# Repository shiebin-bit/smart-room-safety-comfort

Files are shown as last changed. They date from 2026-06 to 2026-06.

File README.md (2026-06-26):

# Smart Room Safety & Comfort Monitoring System

ESP32-based IoT prototype for monitoring room safety and comfort conditions. The system reads temperature, humidity, gas, light and sound signals, shows local status on an OLED display, sends readings to a Flask backend, stores data in SQLite and provides a web dashboard for live monitoring, history and actuator control.

## Features

- Register and login for dashboard users, with password validation
- Multi-device dashboard with pairing-code onboarding
- Live dashboard for latest sensor readings
- Room status classification: `NORMAL`, `WARNING` and `CRITICAL`
- Historical charts for temperature, gas, light and sound
- CSV export for stored sensor history
- SQLite storage with recent data table and summary values
- AUTO and MANUAL control for relay and buzzer output
- Settings drawer for room name, device name, thresholds, LDR dark state and upload interval
- ESP32 captive setup portal for Wi-Fi and pairing code configuration
- Remote WiFi scan, WiFi switch and saved-profile display from the cloud dashboard
- ESP32 OLED display with sensor, status and connection pages
- Push button for changing OLED pages and long-press Wi-Fi setup reset

## Project Structure

```text
.
├── app.py                         Flask API and SQLite backend
├── requirements.txt               Python dependencies
├── SmartRoomSafetyComfort/        ESP32 Arduino sketch
├── static/                        Dashboard CSS and JavaScript
├── templates/                     Flask HTML template
├── circuit/                       Fritzing circuit source and exported diagram image
└── screenshots/                   Dashboard or testing screenshots
```

Generated files such as `smart_room.db`, `logs/`, `.venv/` and `report/` are ignored by Git.

## Hardware

| Component | Connection / Pin |
|---|---|
| ESP32 30-pin Type-C | Main controller |
| OLED SSD1306 | SDA GPIO21, SCL GPIO22, VCC 3.3V, GND |
| DHT11 | OUT GPIO4, VCC 3.3V, GND |
| MQ-2 smoke and gas sensor | AO GPIO34, VCC 5V, GND |
| LDR light sensor module | DO GPIO35, VCC 3.3V, GND |
| Sound sensor module | OUT GPIO32, VCC 3.3V, GND |
| Push button | GPIO27 to GND, uses `INPUT_PULLUP` |
| Active buzzer | GPIO26, GND |
| 1-channel relay module | IN GPIO14, VCC 3.3V, GND |

The relay load should be connected through `COM` and `NO` so the fan or output device stays off by default and turns on only when the relay is activated.

## Power Rails

| Rail | Use |
|---|---|
| 3.3V | OLED, DHT11, LDR, sound sensor and relay |
| 5V/VIN | MQ-2 gas sensor |
| GND | Common ground for all modules |

The relay module was powered from 3.3V in the final prototype because it switched more reliably with the ESP32 GPIO14 output.

The Fritzing source file and exported circuit image are stored in `circuit/`.

## Arduino Setup

Install these libraries from Arduino IDE Library Manager:

- Adafruit SSD1306
- Adafruit GFX Library
- DHT sensor library
- Adafruit Unified Sensor

Use `ESP32 Dev Module` or an equivalent ESP32 DevKit board in Arduino IDE.

The Arduino sketch no longer stores a fixed Wi-Fi SSID, password or laptop IP address in code. On first boot, or after a long press on the push button, the ESP32 starts a setup Wi-Fi network.

1. Upload `SmartRoomSafetyComfort/SmartRoomSafetyComfort.ino`.
2. Open the cloud dashboard at `https://smartroomsafety.shiebindev.com`.
3. Register or login, then click **Add Device**.
4. Copy the pairing code shown by the dashboard.
5. Connect a phone or laptop to the ESP32 setup WiFi, for example `SmartRoom-Setup-xxxx`.
6. The captive portal should open automatically. If it does not, open `http://192.168.4.1`.
7. Select the home WiFi, enter the WiFi password and enter the pairing code.
8. Save and let the ESP32 restart.

The ESP32 sends the pairing code to the Cloudflare backend:

```text
https://smartroomsafety.shiebindev.com
```

After successful pairing, the backend returns the device ID and device token. The ESP32 saves WiFi credentials and device credentials in flash memory using `Preferences`, so the user only needs to configure it once unless the WiFi changes.

## Dashboard Backend

Run the Flask backend from this folder:

```powershell
python -m venv .venv
.\.venv\Scripts\Activate.ps1
pip install -r requirements.txt
python app.py
```

Open the local dashboard:

```text
http://localhost:5000
```

For a public or long-running demo, set a Flask secret key before starting the server:

```powershell
$env:SMARTROOM_SECRET_KEY="change-this-to-a-long-random-value"
$env:SMARTROOM_BACKEND_URL="https://smartroomsafety.shiebindev.com"
python app.py
```

For a phone or ESP32 outside the laptop, expose the Flask server through Cloudflare Tunnel. The ESP32 sketch already uses the project domain internally, so general users do not type the backend URL during setup.

```powershell
cloudflared tunnel --url http://localhost:5000
```

For this project, the permanent Cloudflare route should point to the Flask server:

```text
smartroomsafety.shiebindev.com -> http://localhost:5000
```

## API Endpoints

| Endpoint | Method | Purpose |
|---|---|---|
| `/` | GET | Web dashboard |
| `/login` | GET/POST | User login page |
| `/register` | GET/POST | User registration page |
| `/api/me` | GET | Current dashboard user |
| `/api/devices` | GET/POST | List or add owned ESP32 devices |
| `/api/devices/<device_id>` | PATCH | Update device name and room |
| `/api/device-pair` | POST | Exchange ESP32 pairing code for device credentials |
| `/api/sensor-data` | POST | Receive ESP32 sensor data |
| `/api/latest` | GET | Return latest stored reading |
| `/api/history` | GET | Return historical readings |
| `/api/history/export.csv` | GET | Export selected device history |
| `/api/summary` | GET | Return stored-data summary |
| `/api/settings` | GET/POST | Read or update thresholds and configuration |
| `/api/control` | GET/POST | Read or update relay, buzzer and control mode |
| `/api/device-command` | GET | Plain-text command endpoint for ESP32 |
| `/api/device-status` | POST | Receive WiFi status, scan results and events |
| `/api/wifi/scan` | POST | Queue remote WiFi scan |
| `/api/wifi/connect` | POST | Queue remote WiFi switch |
| `/api/wifi/reconnect` | POST | Queue reconnect using a WiFi profile saved on ESP32 |
| `/api/wifi/forget` | POST | Queue saved WiFi deletion |

## Control Logic

AUTO mode:

```text
NORMAL   -> relay OFF
WARNING  -> relay OFF
CRITICAL -> relay ON
```

MANUAL mode:

```text
Relay switch ON  -> relay output ON
Relay switch OFF -> relay output OFF
Buzzer enabled   -> buzzer can sound in AUTO, or directly controls buzzer in MANUAL
```

## Notes

- LDR module behavior in this prototype is `LOW = bright` and `HIGH = dark`.
- GPIO34 is input-only and is used for MQ-2 analog output.
- GPIO35 is input-only and is used for LDR digital output.
- WiFi passwords are stored locally on the ESP32 after setup. The dashboard only stores SSID names, signal/status data and temporary command state.
- Device tokens are generated by the backend after pairing. Only token hashes are stored in SQLite.
- The report files are intentionally excluded from the GitHub repository.

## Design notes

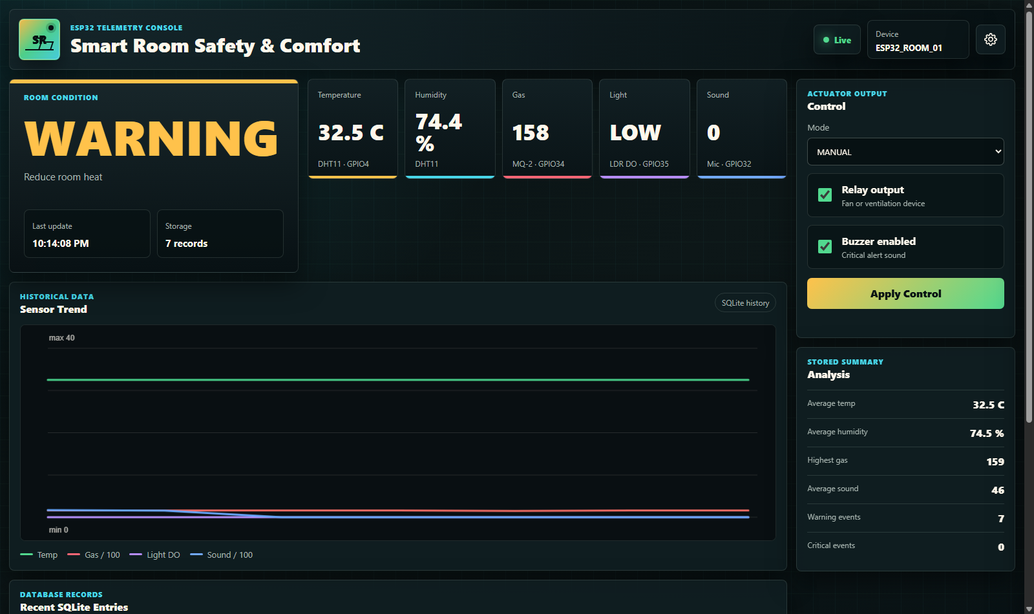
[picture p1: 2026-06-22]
screenshots/dashboard-redesign.png

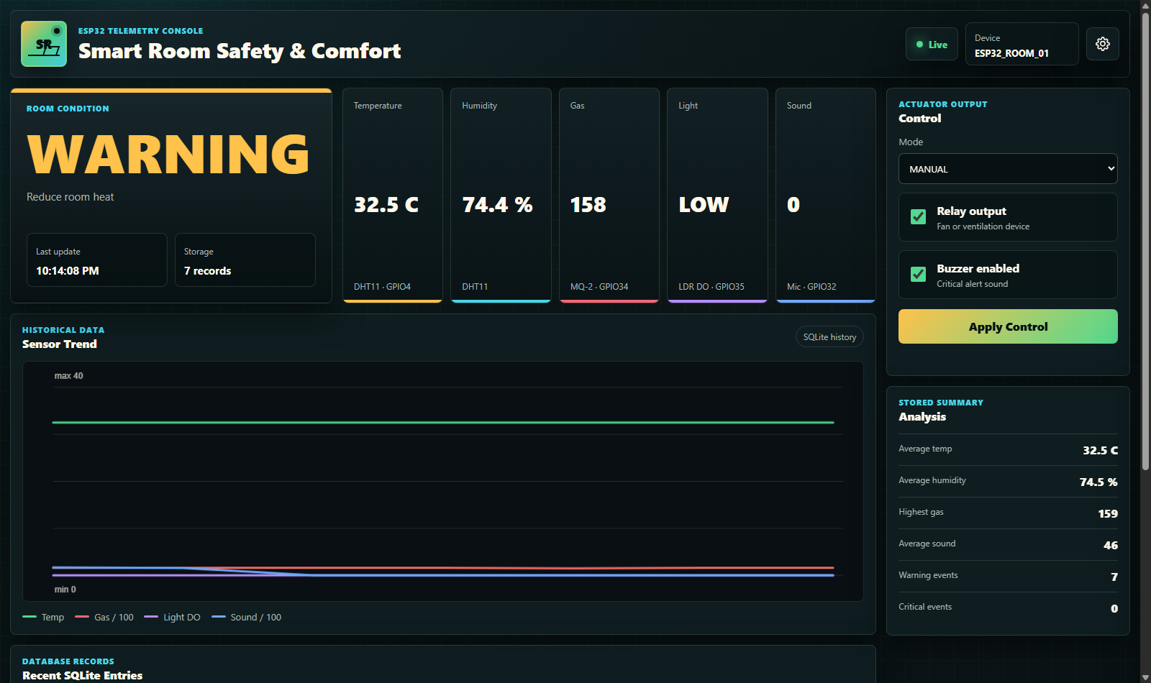
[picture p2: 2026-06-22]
screenshots/dashboard-redesign-final.png

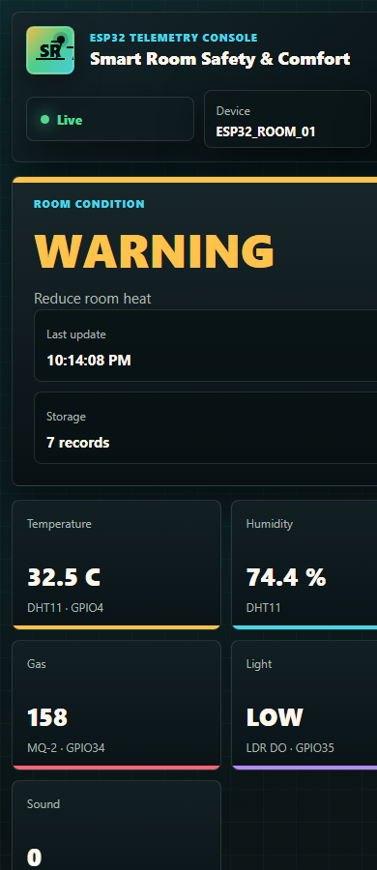
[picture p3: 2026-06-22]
screenshots/dashboard-redesign-mobile.png

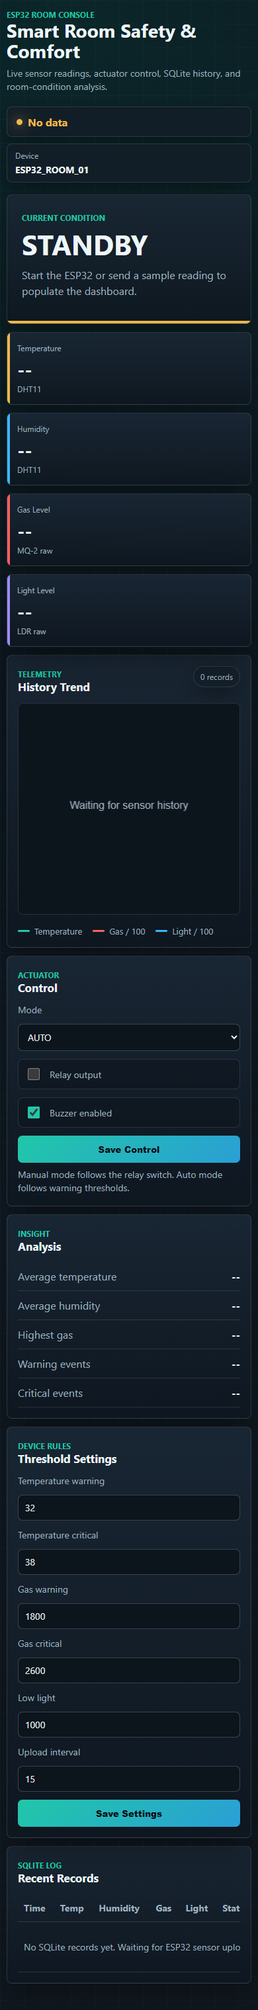
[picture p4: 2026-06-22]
screenshots/dashboard/dashboard-mobile2.png

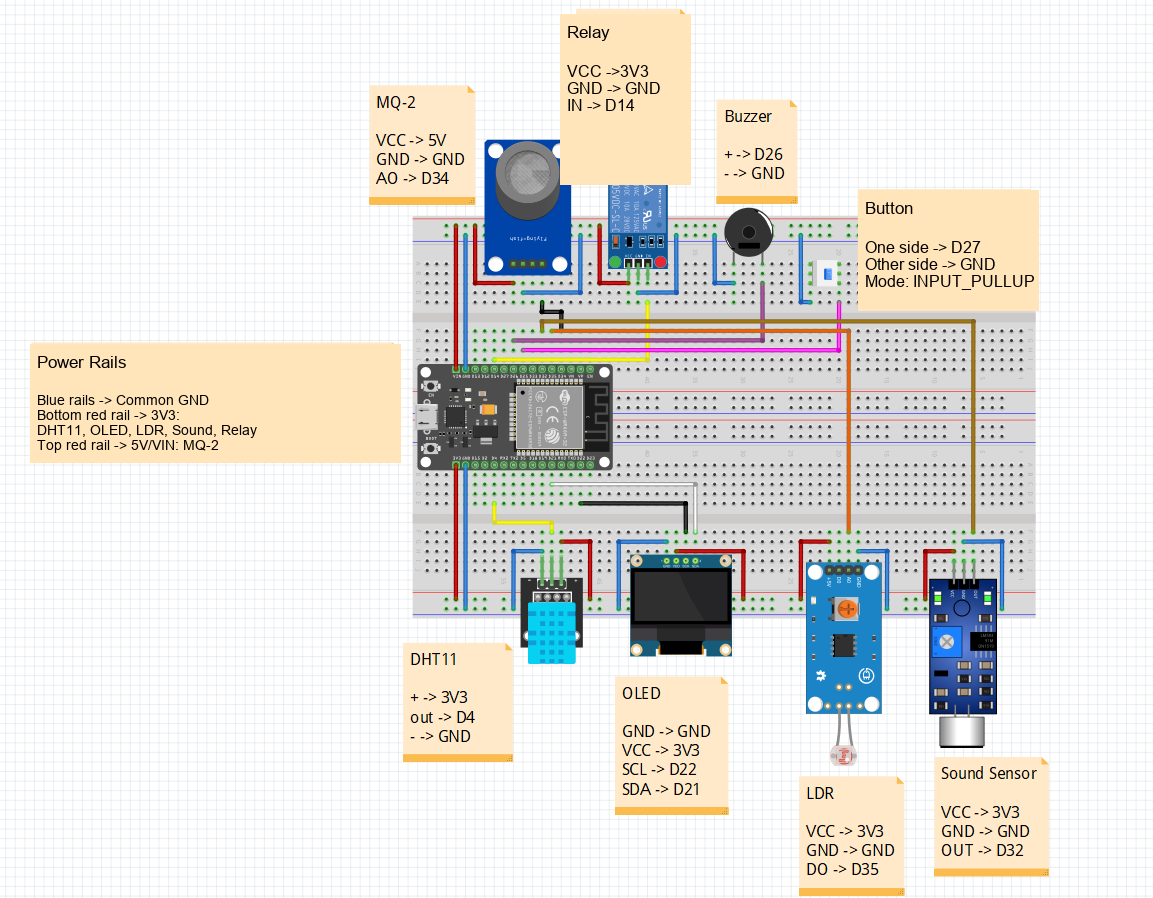
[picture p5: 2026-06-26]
circuit/fritzing-circuit-diagram.png

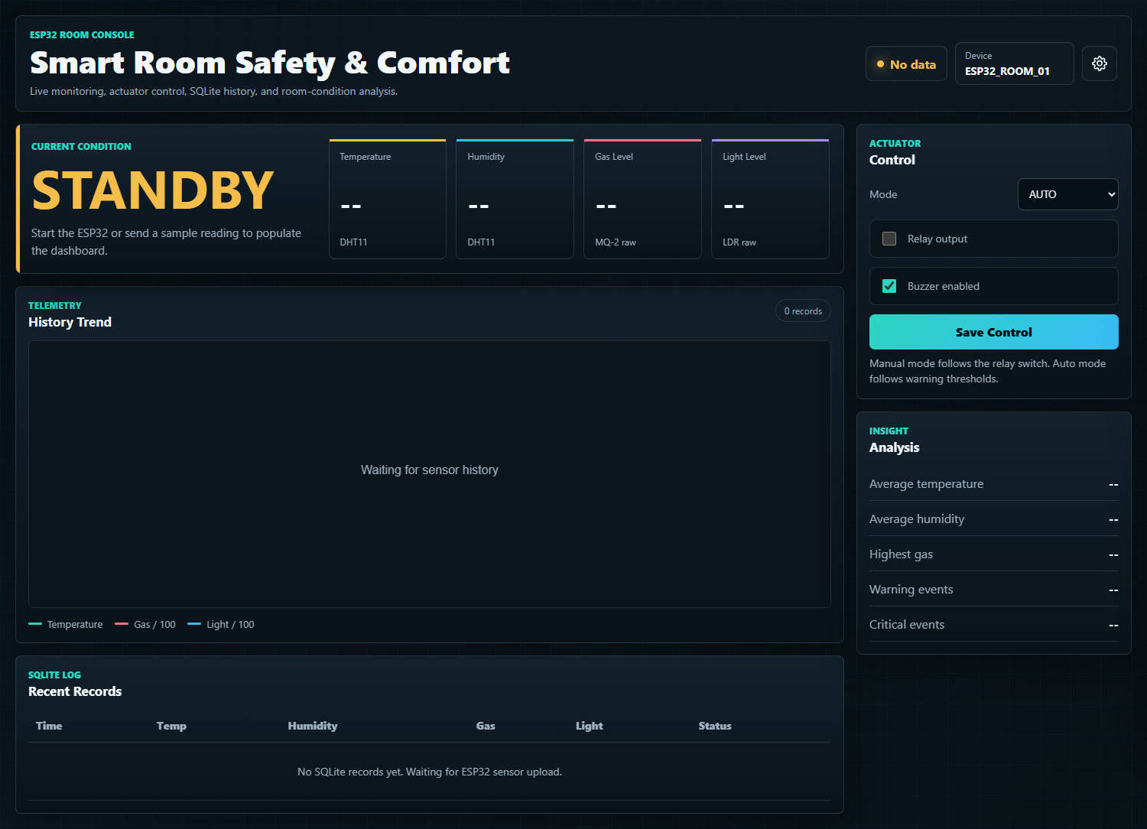
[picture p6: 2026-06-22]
screenshots/dashboard/dashboard-desktop-closed.png

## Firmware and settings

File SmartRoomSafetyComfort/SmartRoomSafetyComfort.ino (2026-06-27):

#include <WiFi.h>
#include <WebServer.h>
#include <DNSServer.h>
#include <HTTPClient.h>
#include <WiFiClientSecure.h>
#include <Preferences.h>
#include <Wire.h>
#include <Adafruit_GFX.h>
#include <Adafruit_SSD1306.h>
#include <DHT.h>

#define OLED_SDA_PIN 21
#define OLED_SCL_PIN 22

#define DHT_PIN 4
#define DHT_TYPE DHT11

#define MQ2_ANALOG_PIN 34
#define LDR_DIGITAL_PIN 35
#define SOUND_DIGITAL_PIN 32

#define BUTTON_PIN 27
#define BUZZER_PIN 26
#define RELAY_PIN 14

const bool RELAY_ACTIVE_LOW = true;

#define SCREEN_WIDTH 128
#define SCREEN_HEIGHT 64
#define OLED_RESET -1
#define OLED_ADDR 0x3C

Adafruit_SSD1306 display(SCREEN_WIDTH, SCREEN_HEIGHT, &Wire, OLED_RESET);
DHT dht(DHT_PIN, DHT_TYPE);
WebServer setupServer(80);
DNSServer dnsServer;
Preferences preferences;
WiFiClientSecure secureClient;

const byte DNS_PORT = 53;
const char *DEFAULT_BACKEND_BASE_URL = "https://smartroomsafety.shiebindev.com";
const char *SAVED_WIFI_PASSWORD_MARKER = "__SAVED_WIFI_PROFILE__";

String wifiSsid = "";
String wifiPassword = "";
String pairingCode = "";
String backendBaseUrl = DEFAULT_BACKEND_BASE_URL;
String deviceId = "UNPAIRED";
String deviceToken = "";

float tempWarningC = 35.0;
float tempCriticalC = 40.0;

int gasWarningRaw = 1800;
int gasCriticalRaw = 2600;
int ldrDarkState = HIGH;

float temperatureC = 0;
float humidityPct = 0;
int gasRaw = 0;
int lightRaw = HIGH;
int soundRaw = 0;

String roomStatus = "STARTING";
String recommendation = "Checking sensors";
String controlMode = "AUTO";

bool manualRelayCommand = false;
bool relayOutputOn = false;
bool buzzerEnabled = true;
bool buzzerShouldAlert = false;
bool buzzerShouldCritical = false;

int oledPage = 0;
const int OLED_PAGE_COUNT = 3;

unsigned long lastSensorReadMs = 0;
unsigned long lastOledUpdateMs = 0;
unsigned long lastUploadMs = 0;
unsigned long lastCommandFetchMs = 0;
unsigned long lastWiFiRetryMs = 0;
unsigned long lastPairRetryMs = 0;
unsigned long lastStatusPostMs = 0;
unsigned long lastButtonChangeMs = 0;
unsigned long buttonPressedAtMs = 0;
unsigned long uploadIntervalMs = 5000;

bool lastButtonReading = HIGH;
bool stableButtonState = HIGH;
bool longPressHandled = false;
bool setupPortalRunning = false;
bool setupSaveRequested = false;

const unsigned long SENSOR_INTERVAL_MS = 2000;
const unsigned long OLED_INTERVAL_MS = 500;
const unsigned long COMMAND_INTERVAL_MS = 5000;
const unsigned long WIFI_RETRY_INTERVAL_MS = 15000;
const unsigned long PAIR_RETRY_INTERVAL_MS = 15000;
const unsigned long STATUS_INTERVAL_MS = 15000;
const unsigned long BUTTON_DEBOUNCE_MS = 50;
const unsigned long BUTTON_LONG_PRESS_MS = 8000;
const int WIFI_PROFILE_COUNT = 6;

void setRelay(bool on);
void setBuzzer(bool on);

void loadDeviceConfig() {
  preferences.begin("smartroom", true);
  wifiSsid = preferences.getString("ssid", "");
  wifiPassword = preferences.getString("password", "");
  pairingCode = preferences.getString("pairing", "");
  backendBaseUrl = preferences.getString("backend", DEFAULT_BACKEND_BASE_URL);
  deviceId = preferences.getString("device_id", "UNPAIRED");
  deviceToken = preferences.getString("token", "");
  preferences.end();
}

void saveSetupConfig(const String &ssid, const String &password, const String &code) {
  String cleanCode = code;
  cleanCode.trim();
  preferences.begin("smartroom", false);
  preferences.putString("ssid", ssid);
  preferences.putString("password", password);
  if (cleanCode.length() > 0) {
    preferences.putString("pairing", cleanCode);
  }
  preferences.putString("backend", DEFAULT_BACKEND_BASE_URL);
  preferences.end();
}

void saveDeviceCredentials(const String &newDeviceId, const String &newToken) {
  String cleanDeviceId = newDeviceId;
  cleanDeviceId.trim();
  String cleanToken = newToken;
  cleanToken.trim();
  preferences.begin("smartroom", false);
  preferences.putString("device_id", cleanDeviceId);
  preferences.putString("token", cleanToken);
  preferences.putString("pairing", "");
  preferences.putString("backend", DEFAULT_BACKEND_BASE_URL);
  preferences.end();
  deviceId = cleanDeviceId;
  deviceToken = cleanToken;
  pairingCode = "";
}

void clearSavedWiFiOnly() {
  preferences.begin("smartroom", false);
  preferences.putString("ssid", "");
  preferences.putString("password", "");
  preferences.end();
  wifiSsid = "";
  wifiPassword = "";
}

void factoryResetDevice() {
  Serial.println("Factory reset requested. Clearing saved WiFi, pairing and device credentials.");
  WiFi.disconnect(true, true);
  preferences.begin("smartroom", false);
  preferences.clear();
  preferences.end();
  wifiSsid = "";
  wifiPassword = "";
  pairingCode = "";
  backendBaseUrl = DEFAULT_BACKEND_BASE_URL;
  deviceId = "UNPAIRED";
  deviceToken = "";
  controlMode = "AUTO";
  manualRelayCommand = false;
  relayOutputOn = false;
  buzzerEnabled = true;
  setRelay(false);
  setBuzzer(false);
}

String htmlEscape(const String &value) {
  String escaped = "";
  for (unsigned int i = 0; i < value.length(); i++) {
    char c = value.charAt(i);
    if (c == '&') escaped += "&amp;";
    else if (c == '<') escaped += "&lt;";
    else if (c == '>') escaped += "&gt;";
    else if (c == '"') escaped += "&quot;";
    else escaped += c;
  }
  return escaped;
}

String jsonEscape(const String &value) {
  String out = "";
  for (unsigned int i = 0; i < value.length(); i++) {
    char c = value.charAt(i);
    if (c == '"' || c == '\\') {
      out += '\\';
    }
    out += c;
  }
  return out;
}

String getJsonString(const String &body, const String &key) {
  String pattern = "\"" + key + "\"";
  int start = body.indexOf(pattern);
  if (start < 0) return "";
  start += pattern.length();
  start = body.indexOf(":", start);
  if (start < 0) return "";
  start++;
  while (start < (int)body.length() && (body.charAt(start) == ' ' || body.charAt(start) == '\n' || body.charAt(start) == '\r' || body.charAt(start) == '\t')) {
    start++;
  }
  if (start >= (int)body.length() || body.charAt(start) != '"') return "";
  start++;
  int end = body.indexOf("\"", start);
  if (end < 0) return "";
  return body.substring(start, end);
}

String getLineValue(const String &text, const String &key) {
  String prefix = key + "=";
  int start = text.indexOf(prefix);
  if (start < 0) return "";
  start += prefix.length();
  int end = text.indexOf('\n', start);
  if (end < 0) end = text.length();
  String value = text.substring(start, end);
  value.trim();
  return value;
}

String digitalLabel(int value) {
  return value == HIGH ? "HIGH" : "LOW";
}

bool parseDigitalState(const String &value, int &target) {
  if (value == "0" || value == "LOW") {
    target = LOW;
    return true;
  }
  if (value == "1" || value == "HIGH") {
    target = HIGH;
    return true;
  }
  return false;
}

void showSetupScreen(const String &apName) {
  display.clearDisplay();
  display.setTextSize(1);
  display.setTextColor(SSD1306_WHITE);
  display.setCursor(0, 0);
  display.println("Setup Mode");
  display.println(apName);
  display.println("Open:");
  display.println("192.168.4.1");
  display.display();
}

String setupPage(const String &apName) {
  int networkCount = WiFi.scanNetworks();
  String options = "";
  for (int i = 0; i < networkCount; i++) {
    String ssid = WiFi.SSID(i);
    options += "<option value=\"" + htmlEscape(ssid) + "\">" + htmlEscape(ssid) + " (" + String(WiFi.RSSI(i)) + " dBm)</option>";
  }
  String page = "<!doctype html><html><head><meta name='viewport' content='width=device-width,initial-scale=1'>";
  page += "<title>Smart Room Setup</title>";
  page += "<style>body{font-family:Arial;background:#071012;color:#fff8ec;margin:0;padding:20px}";
  page += "main{max-width:430px;margin:auto;background:#101d21;border:1px solid #314247;border-radius:8px;padding:20px}";
  page += "label{display:block;margin:14px 0 6px;color:#aab7b2}input,select,button{box-sizing:border-box;width:100%;min-height:42px;border-radius:6px;border:1px solid #40545a;padding:8px;background:#071113;color:#fff8ec}";
  page += ".password-wrap{display:grid;grid-template-columns:1fr 46px;gap:8px}.eye-btn{margin:0;display:grid;place-items:center;background:#13252a;color:#fff8ec}.eye-btn svg{width:20px;height:20px;fill:none;stroke:currentColor;stroke-width:2;stroke-linecap:round;stroke-linejoin:round}";
  page += "button{margin-top:18px;background:#52d98f;color:#061012;font-weight:800}small{color:#aab7b2;line-height:1.5;display:block;margin-top:12px}</style></head><body><main>";
  page += "<h1>Smart Room Setup</h1>";
  page += "<p>Select home WiFi and enter the pairing code shown in the cloud dashboard.</p>";
  page += "<form method='post' action='/save'>";
  page += "<label>Home WiFi</label><select name='ssid'>" + options + "</select>";
  page += "<label>WiFi password</label><div class='password-wrap'><input id='wifi-pass' name='password' type='password' autocomplete='off' autocapitalize='none' spellcheck='false'>";
  page += "<button class='eye-btn' type='button' onclick=\"var p=document.getElementById('wifi-pass');p.type=p.type=='password'?'text':'password';\" aria-label='Show or hide password'><svg viewBox='0 0 24 24'><path d='M2 12s3.5-6 10-6 10 6 10 6-3.5 6-10 6S2 12 2 12Z'></path><circle cx='12' cy='12' r='3'></circle></svg></button></div>";
  if (deviceToken.length() == 0) {
    page += "<label>Pairing code</label><input name='pairing' inputmode='numeric' maxlength='12' required>";
  } else {
    page += "<label>Pairing code</label><input name='pairing' inputmode='numeric' maxlength='12' placeholder='Already paired - optional'>";
  }
  page += "<button type='submit'>Connect Device</button></form>";
  page += "<small>Password is sent only to this ESP32 setup page. After saving, reconnect your phone or laptop to normal WiFi and return to the cloud dashboard.<br><br>Setup WiFi: " + htmlEscape(apName) + "<br>Fallback address: http://192.168.4.1<br>Cloud: " + String(DEFAULT_BACKEND_BASE_URL) + "</small>";
  page += "</main></body></html>";
  return page;
}

void startSetupPortal() {
  setupPortalRunning = true;
  setupSaveRequested = false;
  WiFi.mode(WIFI_AP_STA);
  String apName = "SmartRoom-Setup-" + String((uint32_t)ESP.getEfuseMac(), HEX);
  WiFi.softAP(apName.c_str());
  delay(200);
  dnsServer.start(DNS_PORT, "*", WiFi.softAPIP());

  setupServer.on("/", HTTP_GET, [apName]() {
    setupServer.send(200, "text/html", setupPage(apName));
  });
  setupServer.on("/generate_204", HTTP_GET, []() {
    setupServer.sendHeader("Location", "http://192.168.4.1/", true);
    setupServer.send(302, "text/plain", "");
  });
  setupServer.on("/fwlink", HTTP_GET, []() {
    setupServer.sendHeader("Location", "http://192.168.4.1/", true);
    setupServer.send(302, "text/plain", "");
  });
  setupServer.on("/hotspot-detect.html", HTTP_GET, [apName]() {
    setupServer.send(200, "text/html", setupPage(apName));
  });
  setupServer.on("/save", HTTP_POST, []() {
    String ssid = setupServer.arg("ssid");
    String password = setupServer.arg("password");
    String code = setupServer.arg("pairing");
    if (ssid.length() == 0) {
      setupServer.send(400, "text/html", "<h1>Missing WiFi</h1><p>Please select a WiFi network.</p><p><a href='/'>Back</a></p>");
      return;
    }
    saveSetupConfig(ssid, password, code);
    setupSaveRequested = true;
    setupPortalRunning = false;
    setupServer.send(200, "text/html", "<!doctype html><html><head><meta name='viewport' content='width=device-width,initial-scale=1'><style>body{font-family:Arial;background:#071012;color:#fff8ec;padding:22px}main{max-width:430px;margin:auto}</style></head><body><main><h1>Saved</h1><p>ESP32 will restart in a few seconds, connect to your WiFi and pair with the cloud dashboard.</p><p>Reconnect your phone or laptop to normal WiFi, then return to the cloud dashboard.</p><p>If SmartRoom-Setup appears again after 30 seconds, WiFi connection or pairing code failed. Reopen this page and check the password and pairing code.</p></main></body></html>");
  });
  setupServer.onNotFound([apName]() {
    setupServer.send(200, "text/html", setupPage(apName));
  });

  setupServer.begin();
  Serial.print("Setup portal started. AP: ");
  Serial.println(apName);
  Serial.println("Open http://192.168.4.1");
  showSetupScreen(apName);

  while (setupPortalRunning) {
    dnsServer.processNextRequest();
    setupServer.handleClient();
    delay(5);
  }
  if (setupSaveRequested) {
    delay(6000);
    WiFi.softAPdisconnect(true);
    WiFi.mode(WIFI_STA);
    ESP.restart();
  }
}

bool beginHttp(HTTPClient &http, const String &url) {
  if (url.startsWith("https://")) {
    secureClient.setInsecure();
    return http.begin(secureClient, url);
  }
  return http.begin(url);
}

void addDeviceTokenHeader(HTTPClient &http) {
  if (deviceToken.length() > 0) {
    http.addHeader("X-Device-Token", deviceToken);
  }
}

void saveWifiProfile(const String &ssid, const String &password) {
  preferences.begin("smartroom", false);
  for (int i = 0; i < WIFI_PROFILE_COUNT; i++) {
    String key = "p" + String(i) + "_ssid";
    if (preferences.getString(key.c_str(), "") == ssid || preferences.getString(key.c_str(), "").length() == 0) {
      preferences.putString(key.c_str(), ssid);
      preferences.putString(("p" + String(i) + "_pass").c_str(), password);
      preferences.putUInt(("p" + String(i) + "_fail").c_str(), 0);
      preferences.end();
      return;
    }
  }
  preferences.putString("p0_ssid", ssid);
  preferences.putString("p0_pass", password);
  preferences.putUInt("p0_fail", 0);
  preferences.end();
}

void forgetWifiProfile(const String &ssid) {
  preferences.begin("smartroom", false);
  for (int i = 0; i < WIFI_PROFILE_COUNT; i++) {
    String key = "p" + String(i) + "_ssid";
    if (preferences.getString(key.c_str(), "") == ssid) {
      preferences.putString(key.c_str(), "");
      preferences.putString(("p" + String(i) + "_pass").c_str(), "");
      preferences.putUInt(("p" + String(i) + "_fail").c_str(), 0);
    }
  }
  preferences.end();
}

bool getSavedWifiPassword(const String &ssid, String &password) {
  String targetSsid = ssid;
  targetSsid.trim();
  Serial.print("Reconnect requested for saved SSID: ");
  Serial.println(targetSsid);
  if (targetSsid == wifiSsid && wifiPassword.length() > 0) {
    Serial.println("Using current WiFi password from active config.");
    password = wifiPassword;
    return true;
  }
  preferences.begin("smartroom", true);
  Serial.println("Saved WiFi profiles on ESP32:");
  for (int i = 0; i < WIFI_PROFILE_COUNT; i++) {
    String savedSsid = preferences.getString(("p" + String(i) + "_ssid").c_str(), "");
    savedSsid.trim();
    if (savedSsid.length() > 0) {
      Serial.print(" - ");
      Serial.println(savedSsid);
    }
    if (savedSsid == targetSsid) {
      password = preferences.getString(("p" + String(i) + "_pass").c_str(), "");
      preferences.end();
      Serial.println(password.length() > 0 ? "Saved password found." : "Saved profile is an open network.");
      return true;
    }
  }
  preferences.end();
  Serial.println("Saved password not found on ESP32.");
  return false;
}

bool tryConnect(const String &ssid, const String &password, unsigned long timeoutMs) {
  if (ssid.length() == 0) return false;
  WiFi.mode(WIFI_STA);
  WiFi.begin(ssid.c_str(), password.c_str());
  unsigned long start = millis();
  Serial.print("Connecting to ");
  Serial.print(ssid);
  while (WiFi.status() != WL_CONNECTED && millis() - start < timeoutMs) {
    delay(500);
    Serial.print(".");
  }
  Serial.println();
  if (WiFi.status() == WL_CONNECTED) {
    Serial.print("WiFi connected. IP: ");
    Serial.println(WiFi.localIP());
    wifiSsid = ssid;
    wifiPassword = password;
    preferences.begin("smartroom", false);
    preferences.putString("ssid", ssid);
    preferences.putString("password", password);
    preferences.end();
    saveWifiProfile(ssid, password);
    return true;
  }
  return false;
}

bool connectWiFi() {
  if (WiFi.status() == WL_CONNECTED) return true;
  if (wifiSsid.length() > 0 && tryConnect(wifiSsid, wifiPassword, 15000)) return true;

  preferences.begin("smartroom", true);
  for (int i = 0; i < WIFI_PROFILE_COUNT; i++) {
    String ssid = preferences.getString(("p" + String(i) + "_ssid").c_str(), "");
    String pass = preferences.getString(("p" + String(i) + "_pass").c_str(), "");
    if (ssid.length() > 0 && tryConnect(ssid, pass, 12000)) {
      preferences.end();
      return true;
    }
  }
  preferences.end();

  Serial.println("No saved WiFi works. Starting setup portal.");
  startSetupPortal();
  return false;
}

bool pairDevice() {
  if (deviceToken.length() > 0) return true;
  if (pairingCode.length() == 0) {
    Serial.println("No pairing code available.");
    startSetupPortal();
    return false;
  }
  if (WiFi.status() != WL_CONNECTED) return false;

  HTTPClient http;
  String url = String(DEFAULT_BACKEND_BASE_URL) + "/api/device-pair";
  if (!beginHttp(http, url)) return false;
  http.addHeader("Content-Type", "application/json");
  String payload = "{\"pairing_code\":\"" + jsonEscape(pairingCode) + "\"}";
  int httpCode = http.POST(payload);
  String body = http.getString();
  Serial.print("PAIR -> ");
  Serial.println(httpCode);
  if (httpCode != 200) {
    Serial.print("PAIR body: ");
    Serial.println(body.substring(0, 160));
  }
  http.end();

  if (httpCode == 200) {
    String newDeviceId = getJsonString(body, "device_id");
    String newToken = getJsonString(body, "device_token");
    if (newDeviceId.length() > 0 && newToken.length() > 0) {
      saveDeviceCredentials(newDeviceId, newToken);
      Serial.print("Paired device ID: ");
      Serial.println(deviceId);
      return true;
    }
    Serial.println("PAIR parse failed. Response body:");
    Serial.println(body.substring(0, 240));
  }

  display.clearDisplay();
  display.setCursor(0, 0);
  display.setTextColor(SSD1306_WHITE);
  display.setTextSize(1);
  display.println("Pairing failed");
  if (httpCode == 400 || httpCode == 404) {
    display.println("Check code");
    display.display();
    delay(1500);
    startSetupPortal();
  } else {
    display.println("Cloud retry");
    display.display();
  }
  return false;
}

void setRelay(bool on) {
  relayOutputOn = on;
  digitalWrite(RELAY_PIN, RELAY_ACTIVE_LOW ? (on ? LOW : HIGH) : (on ? HIGH : LOW));
}

void setBuzzer(bool on) {
  digitalWrite(BUZZER_PIN, on ? HIGH : LOW);
}

void updateBuzzer() {
  if (controlMode == "MANUAL") setBuzzer(buzzerEnabled);
  else if (!buzzerEnabled) setBuzzer(false);
  else if (buzzerShouldCritical) setBuzzer(true);
  else if (buzzerShouldAlert) setBuzzer((millis() / 500) % 2 == 0);
  else setBuzzer(false);
}

void updateRelayOutput() {
  if (controlMode == "MANUAL") setRelay(manualRelayCommand);
  else setRelay(roomStatus == "CRITICAL");
}

void classifyRoom() {
  bool gasCritical = gasRaw >= gasCriticalRaw;
  bool gasWarning = gasRaw >= gasWarningRaw;
  bool tempCritical = temperatureC >= tempCriticalC;
  bool tempWarning = temperatureC >= tempWarningC;
  bool lowLight = lightRaw == ldrDarkState;

  if (gasCritical || tempCritical) {
    roomStatus = "CRITICAL";
    recommendation = gasCritical ? "Ventilate room now" : "Turn on cooling";
  } else if (gasWarning || tempWarning || lowLight) {
    roomStatus = "WARNING";
    if (gasWarning) recommendation = "Improve ventilation";
    else if (tempWarning) recommendation = "Reduce room heat";
    else recommendation = "Increase lighting";
  } else {
    roomStatus = "NORMAL";
    recommendation = "Room condition OK";
  }

  buzzerShouldAlert = roomStatus == "WARNING" || roomStatus == "CRITICAL";
  buzzerShouldCritical = roomStatus == "CRITICAL";
  updateRelayOutput();
  updateBuzzer();
}

void readSensors() {
  float t = dht.readTemperature();
  float h = dht.readHumidity();
  if (!isnan(t)) temperatureC = t;
  if (!isnan(h)) humidityPct = h;
  gasRaw = analogRead(MQ2_ANALOG_PIN);
  lightRaw = digitalRead(LDR_DIGITAL_PIN);
  soundRaw = digitalRead(SOUND_DIGITAL_PIN);
  classifyRoom();

  Serial.print("Temp: ");
  Serial.print(temperatureC);
  Serial.print(" C, Humidity: ");
  Serial.print(humidityPct);
  Serial.print(" %, Gas: ");
  Serial.print(gasRaw);
  Serial.print(", Light: ");
  Serial.print(digitalLabel(lightRaw));
  Serial.print(", Sound: ");
  Serial.print(digitalLabel(soundRaw));
  Serial.print(", Relay: ");
  Serial.print(relayOutputOn ? "ON" : "OFF");
  Serial.print(", Status: ");
  Serial.println(roomStatus);
}

void drawHeader(const String &title) {
  display.clearDisplay();
  display.setTextSize(1);
  display.setTextColor(SSD1306_WHITE);
  display.setCursor(0, 0);
  display.println(title);
  display.drawLine(0, 10, 127, 10, SSD1306_WHITE);
}
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
void loop() {
  handleButton();
  updateRelayOutput();
  updateBuzzer();

  unsigned long now = millis();

  if (WiFi.status() != WL_CONNECTED && now - lastWiFiRetryMs >= WIFI_RETRY_INTERVAL_MS) {
    lastWiFiRetryMs = now;
    connectWiFi();
  }
  if (WiFi.status() == WL_CONNECTED && deviceToken.length() == 0 && pairingCode.length() > 0 && now - lastPairRetryMs >= PAIR_RETRY_INTERVAL_MS) {
    lastPairRetryMs = now;
    pairDevice();
  }
  if (now - lastSensorReadMs >= SENSOR_INTERVAL_MS) {
    lastSensorReadMs = now;
    readSensors();
  }
  if (now - lastOledUpdateMs >= OLED_INTERVAL_MS) {
    lastOledUpdateMs = now;
    updateOled();
  }
  if (now - lastUploadMs >= uploadIntervalMs) {
    lastUploadMs = now;
    uploadData();
  }
  if (now - lastCommandFetchMs >= COMMAND_INTERVAL_MS) {
    lastCommandFetchMs = now;
    fetchBackendCommand();
  }
  if (now - lastStatusPostMs >= STATUS_INTERVAL_MS) {
    lastStatusPostMs = now;
    postDeviceStatus(WiFi.status() == WL_CONNECTED ? "CONNECTED" : "DISCONNECTED", WiFi.status() == WL_CONNECTED ? "" : "WiFi disconnected");
  }
}

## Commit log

2026-06-22 Initial smart room IoT project
    [Sensor assignment 3.fzz]
2026-06-26 Add commercial IoT dashboard and onboarding flow
    [Sensor assignment 3.fzz]
2026-06-27 Update ESP32 reset flow and thresholds
    [SmartRoomSafetyComfort.ino]
